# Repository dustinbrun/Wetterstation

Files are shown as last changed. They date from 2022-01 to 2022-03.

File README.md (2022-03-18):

# Wetterstation
MQTT-Wetterstation mit Datenauswertung und -Darstellung in Node-Red sowie Aufzeichung durch Influx-DB.

Dieses Projekt besteht aus mehreren Teilen:

## 1. [Grundlagen: VEML 6070 Sensor, UV-Index Berechnung](VEML_6070/README.md)
## 2. [Bresser Wetterstation MQTT-Anbindung mit RTL-433](rtl_433_Bresser/README.md)
## 3. [Erweiterung der Bresser Wetterstation: ESP8266-Wettersensoren](ESP8266/README.md)
## 4. [Zusatzinfos: verwendete Berechnungsformeln](Berechnungsfunktionen.md)

<br><br>
<p xmlns:dct="http://purl.org/dc/terms/" xmlns:cc="http://creativecommons.org/ns#" class="license-text">This work by <span property="cc:attributionName">Dustin Brunner</span> is licensed under <a rel="license" href="https://creativecommons.org/licenses/by/4.0">CC BY 4.0</a></p>

<br />Dieses Werk von <span xmlns:cc="http://creativecommons.org/ns#" property="cc:attributionName">Dustin Brunner</span> ist lizenziert unter einer <a rel="license" href="http://creativecommons.org/licenses/by/4.0/">Creative Commons Namensnennung 4.0 International Lizenz</a>.

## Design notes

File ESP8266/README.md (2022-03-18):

# ESP8266 MQTT Wetterstation

Wie man eine Wetterstation basierend auf einem ESP8266 baut...

Der ESP verbindet sich per WLAN mit einem MQTT-Server und sendet die Messwerte als JSON (alle 10 Minuten), welche dann in Node-Red empfangen und verarbeitet werden. Zusätzlich werden die Daten in eine Influx-DB Datenbank geschrieben und können in Grafana visualisiert werden.

Diese Wetterstation kann als Erweiterung der Bresser-Wetterstation gesehen werden. Es werden Funktionen hinzugefügt, welche über die Bresser-Wetterstation nicht gemessen und empfangen werden können.

# Die Sensoren
| Sensor	| Protocol	| Values |
| --- |--- | --- |
| BME 280 | I2C | Temperatur (nicht genutzt da nicht exakt), Luftfeuchtigkeit (nicht genutzt da von Bresser-Station gemesssen), Luftdruck |
| 2x DS18B20 | OneWire Bus | Temperatur (2m und 0m Höhe) |
| BH1750 | I2C | Helligkeit |
| Rain sensor | Analog in | Regen ja/nein |
| VEML6070 | I2C | UV-Intensität (daraus kann der UV-Index berechnet werden) |

<br>

# Hardware
Es wird ein WeMos D1 Mini Board verwendet. Das PCB-Layout passt (nur) für dieses Board.
## Schaltplan
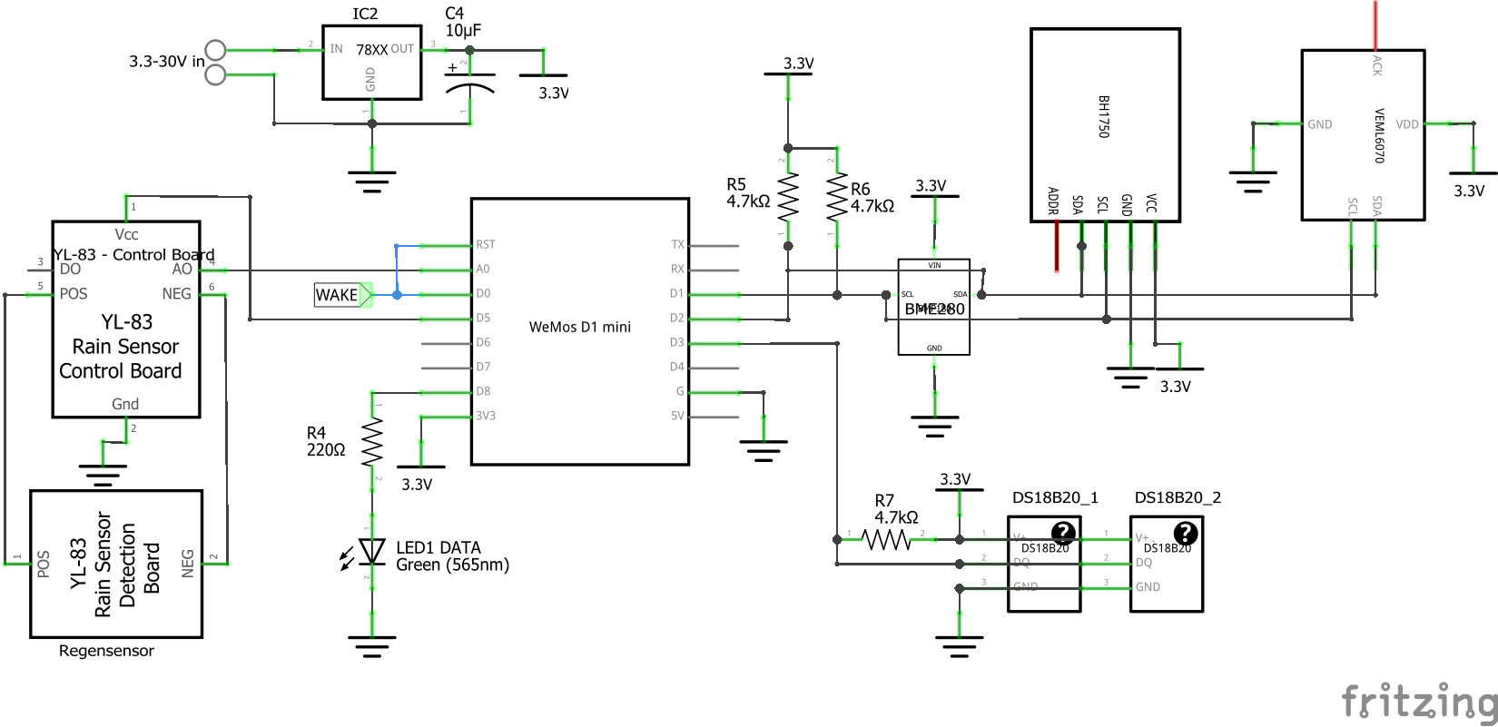
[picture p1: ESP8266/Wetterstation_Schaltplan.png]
[](Wetterstation_Schaltplan.png)

## Hauptplatine
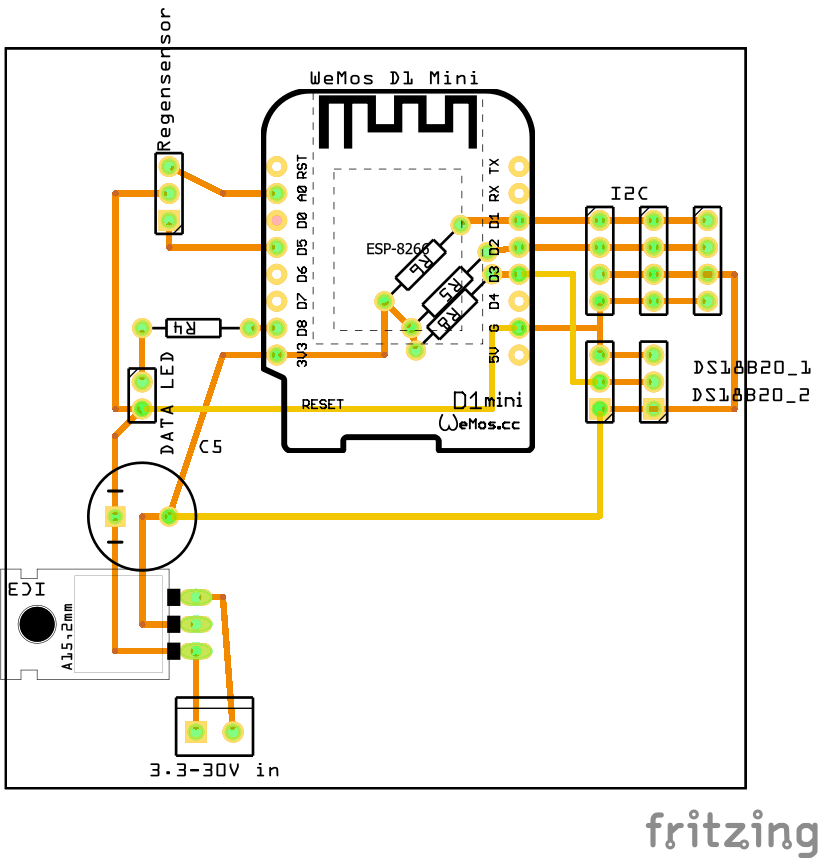
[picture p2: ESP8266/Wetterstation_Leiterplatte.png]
[](Wetterstation_Leiterplatte.png)

## 3D gedruckte Teile
Im Internet habe ich einen sog. Stevenson-Screen gefunden, welcher als Sonnenschutz-Gehäuse für den BME280 und die DS18B20 Sensoren dient.

Für die beiden Lichtsensoren habe ich jeweils ein Gehäuse erstellt, welche z.B. mit einem Stück Plexiglas geschlossen oder für noch besseren Feuchtigkeitsschutz mit transparenten Epoxidharz ausgegossen werden können. 
Die Modelle können aus der GitHub repository heruntergeladen werden. Das Lichtsensor Gehäuse ist auch auf Tinkercad verfügbar:  https://www.tinkercad.com/things/6c97AcGgvdE 

<br>

# Software
## ESP8266
-	Es wird bei jeder Messung ein Mittelwert aus 3 Messungen gebildet
-	Der Luftdruck auf NN-Niveau wird berechnet. (Im Programmcode muss die Aufstellhöhe der Station angepast werden, damit dieser Wert korrekt berechnet werden kann)
-	Es sind einige Debugging-Funktionen implementiert: ESP Reset, Ping/Pong, WIFI Signalstärke
-	Debug LED
bootup: ein
nach Initialisierung: blinkt 2x
error, MQTT nicht verbunden: dauer ein
-	Damit die DS18B20 Sensoren funktionieren müssen die Sensoradressen im Code angepasst werden. Diese Adressen können mit Beispielcode `oneWireSearch.ino` der DallasTemperature Bibiliothek in Erfahrung gebracht werden.
- Alle benötigten Bibiliotheken sind im Code verlinkt und können von dort heruntergeladen werden.

Achtung: Damit die Datenübertragung mit JSON funktioniert muss die zulässige Paketgröße `MQTT_MAX_PACKET_SIZE` in der `PubSubClient.h` Datei auf `1024` erhöht werden. Diese Datei ist unter Windows zu finden unter: `C:\Users\*YOUR_USERNAME*\Documents\Arduino\libraries\pubsubclient-master\src\PubSubClient.h`

## Datenverarbeitung: Node-Red
Die Auswertung der Messwerte erfolgt in Node-Red.
Ich habe einen Flow erstellt, welcher die Werte im Node-Red Dashboard grafisch darstellt sowie in eine Influx-DB Datenbank schreibt. Somit ist eine weitere Auswertung mit Grafana möglich. In Node-Red wird ebenfalls die Berechnung des UV-Risikofaktors (UV-Index) durchgeführt. Die Messwerte werden in globale Variablen geschieben, sodass sie innerhalb von Node-Red weiterverwendet werden können (z.B. für das [MQTT Weather Display](https://github.com/dustinbrun/MQTT-Weather-display))

[Screenshot des Node-Red Flows](Node-Red/node-red-flow.PNG)

Der Flow kann aus der Github Repository heruntergeladen werden.

# Quellen
-	https://github.com/jp112sdl/HB-UNI-Sen-WEA 
-	Rain sensor:	https://www.heise.de/developer/artikel/Darf-es-etwas-mehr-sein-Anschluss-von-Umweltsensoren-3339616.html 
-	MQTT: https://randomnerdtutorials.com/esp8266-and-node-red-with-mqtt/ 
-	BME280, debug functions: https://github.com/adlerweb/ESP8266-BME280-Multi/blob/master/src/main.cpp 
-	Stevenson Screen: https://www.thingiverse.com/thing:2755149 
-	Weitere Quellen (Bibiliotheken etc.) sind im Code verlinkt

<br><br>
<p xmlns:dct="http://purl.org/dc/terms/" xmlns:cc="http://creativecommons.org/ns#" class="license-text">This work by <span property="cc:attributionName">Dustin Brunner</span> is licensed under <a rel="license" href="https://creativecommons.org/licenses/by/4.0">CC BY 4.0</a></p>

<br />Dieses Werk von <span xmlns:cc="http://creativecommons.org/ns#" property="cc:attributionName">Dustin Brunner</span> ist lizenziert unter einer <a rel="license" href="http://creativecommons.org/licenses/by/4.0/">Creative Commons Namensnennung 4.0 International Lizenz</a>.

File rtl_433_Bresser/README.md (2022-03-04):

# Bresser Wetterstation MQTT
Viele Wetterstationen können mit Hilfe der Software rtl_433 emfangen werden.
rtl_433 wird hierbei als Brücke zwischen dem Signal der Wetterstation (868MHz) und dem MQTT-Server verwendet.
Ich verwende eine `Bresser 5-in-1 Wetter Center`-Station ([Link](https://www.bresser.de/Wetter-Zeit/BRESSER-5-in-1-Wetter-Center-schwarz.html)). rtl_433 ist aber ebenfalls mit vielen anderen Wettersationen kompatibel. Dazu einfach einen Blick in die Dokumentation werfen.

Der Empfang erfolgt mit Hilfe eines SDR-USB Sticks (auch ein DVBT-Stick mit RTL2832-Chipsatz ist möglich).

------------------

# Installation von rtl_433

Link zur Software: https://github.com/merbanan/rtl_433

Die Software kann z.B. auf einem Raspberry Pi oder innerhalb einer Virtuellen Maschine (VM, Ubuntu 20.04 server) erfolgen.

rtl_433 kann als Linux-Paket installiert werden (unter Debian mit `apt-get install rtl-433`). In meinem Fall konnte mit dieser Version jedoch keine erfolgreiche Decodierung erreicht werden. Deshalb der Weg über die manuelle Compillierung, welche bei mir die Wetterstation auf Anhieb erfolgreich empfangen konnte.

Zur Verwendung des SDR-Sticks zunächst folgende Vorkehrungen treffen:

In die Datei
```
sudo nano /etc/modprobe.d/blacklist.conf
```
folgende Einträge ergänzen:
```
# Blacklist DVBT-SDR Stick (disable the Stick for DVBT)
blacklist dvb_usb_rtl28xxu
blacklist rtl2832
blacklist rtl2830
```

Nun kann der SDR-Stick eingesteckt und mit der eigentlichen Installation begonnen werden. Die hier angegeben Paketversionen müssen nicht zwangsläufig verwendet werden funktionierten in meinem Fall jedoch auf Anhieb.
```
sudo apt-get install git libtool=2.4.6-14 libusb-1.0-0-dev=2:1.0.23-2build1 librtlsdr-dev=0.6.0-3 rtl-sdr=0.6.0-3 build-essential cmake pkg-config

git clone https://github.com/merbanan/rtl_433.git
cd rtl_433/
mkdir build
cd build
cmake ..
make
sudo make install
```

Die Funtkion des SDR-Sticks kann mit Hilfe des Befehls `rtl_test -t` geprüft werden.

# Testen des Empfangs
Als Antenne kann bei geringer Entfernung zur Wetterstation die dem DVBT-Stick mitgelieferte Antenne verwendet werden. 
Anderenfalls empfiehlt es sich eine `868MHz` Groundplane-Antenne zu bauen (Quelle: https://www.darc.de/fileadmin/filemounts/distrikte/o/ortsverbaende/38/Downloads/Bericht_868MHz_Antennen_V2.0.pdf):

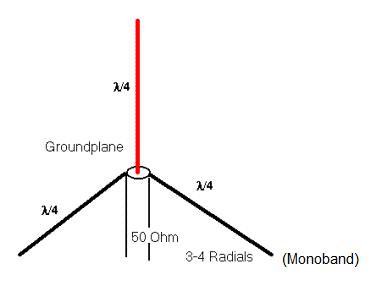
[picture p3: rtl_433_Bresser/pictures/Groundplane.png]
[](pictures/Groundplane.png)
([Bildquelle](http://sites.prenninger.com/elektronik/dvb-t-antennen/groundplane))

Für die Frequenz `868MHz` beträgt die Länge eines einzelnen Drahtes `lambda/4 = 1/4 * 300/868MHz * 0.96 = 8,29cm`.

Mit der passenden Antenne kann nun ein erster Empfangstest stattfinden:

```
rtl_433 -f 868M
```
Nach wenigen Sekunden/Minuten sollte ein erfolgreicher Empfang zustande gekommen sein. Die Ausgabe zeigt die Decodierten Messwerte:
```
time      : 2021-12-30 10:05:47
model     : Bresser-6in1  id        : 27384665
channel   : 0             Battery   : 1             Temperature: 19.8 C
Humidity  : 53            Sensor type: 1            Wind Gust : 0.8 m/s
Wind Speed: 0.8 m/s       Direction : 144           Integrity : CRC
```
Es kann teilweise vorkommen, dass in einer Nachricht nicht alle Messwerte gesendet werden.
Der Empfang kann mit `STRG-C` beendet werden.

# Produktivbetrieb mit MQTT
Die Einstellungen für den Betrieb werden in einer Konfigurationsdatei festgelegt. Dafür wird zunächst die Beispieldatei in das Programmverzeichnis kopiert und anschließend geöffnet.
```
sudo mkdir /etc/rtl_433
sudo cp conf/rtl_433.example.conf /etc/rtl_433/rtl_433.conf
sudo nano /etc/rtl_433/rtl_433.conf
```
In dieser Datei folgende Zeilen auskommentieren und anpassen:
```
frequency     868M          # Empfangsfrequenz der Wetterstation
sample_rate   1000000
report_meta   time:iso      # Fomat des Zeitstempels ISO
output        mqtt://---MQTT-SERVER-IP---:1883,user=USERNAME,pass=PASSWORD,retain=0,devices=rtl_433[/protocol]       # Ausgabe mit MQTT
```
Achtung: Bei dieser Art der Konfiguration kann es vorkommen, dass auch andere Wettersationen des gleichen Typs empfangen werden, sofern sie in Reichweite des Empfängers sind. Dies kann durch einen Abgleich der `id` der eigenen Station vermieden werden. Zu beachten ist dabei jedoch, dass sich die id nach jedem Reset bzw. Batteriewechsel ändert und damit jedes mal eine erneute Konfigurationsänderung nöitg ist.

Damit nur die Eigene Wetterstation (bzw. nur Sationen des gleichen Typs wie die eigene) empfangen wird, können in der Datei alle Protokolle außer das benötigte auskommentiert (`#` vor jede Zeile) oder gelöscht werden. Die einzige benötigte Zeile für diese Wetterstation muss erhalten bleiben:
```
protocol 172 # Bresser Weather Center 6-in-1, 7-in-1 indoor, new 5-in-1, 3-in-1 wind gauge, Froggit WH6000, Ventus C8488A
```

Nun kann diese Datei gespeichert und geschlossen werden. 

Es wird zuletzt noch der automatische Start beim Hochfahren konfiguriert:
```
sudo nano /etc/systemd/system/rtl_433-mqtt.service
```
In diese Datei wird der folgende Inhalt eingefügt und gespeichert:
```
[Unit]
Description=rtl_433 to MQTT publisher
After=network.target
[Service]
ExecStart=/usr/local/bin/rtl_433
Restart=always
RestartSec=5
[Install]
WantedBy=multi-user.target
```
Nun kann der Autostart aktiviert werden:
```
sudo systemctl enable rtl_433-mqtt.service
sudo systemctl start rtl_433-mqtt.service
sudo systemctl status rtl_433-mqtt.service
```
(Eine Deaktivierung kann mit `sudo systemctl disable rtl_433-mqtt.service` erfolgen.)

rtl_433 erzeugt nun für jeden Messwert eine MQTT-Nachricht. Der Name des MQTT-Topics entspricht dabei dem Messwertname, z.B. `rtl_433/172/wind_avg_m_s` oder `rtl_433/172/temperature_C`.

# Datenverarbeitung mit Node-Red
rtl_433 erzeugt bei jeder Nachricht für jeden Messwert eine MQTT-Nachricht, welche mit Node-Red weiterverarbeitet werden kann. Ich habe einen Node-Red-Flow erstellt, welcher die Messwerte im Node-Red-Dashboard darstellt sowie in eine Influx-DB Datenbank schreibt. Somit ist auch eine Visualisierung mit Grafana möglich. In Node-Red erfolgt ebenfalls die Berechnung von Taupunkt und Hitzeindex (gefühlte Temperatur) aus den Messwerten sowie eine Umrechung der Windgeschwindigkeit in km/h und eine entsprechende Windstärke (Beaufortskala). 

[Screenshot des Node-Red-Flows](pictures/node_red_flow.png)

Der Flow (`wetter_bresser_node_red_flow.json`) kann aus der Github-Repository heruntergeladen und importiert werden. Es werden folgende Erweiterungs-Nodes benötigt: node-red-dashboard, node-red-contrib-influxdb und node-red-contrib-calculate.

<br>
<br>
<p xmlns:dct="http://purl.org/dc/terms/" xmlns:cc="http://creativecommons.org/ns#" class="license-text">This work by <span property="cc:attributionName">Dustin Brunner</span> is licensed under <a rel="license" href="https://creativecommons.org/licenses/by/4.0">CC BY 4.0</a></p>

<br />Dieses Werk von <span xmlns:cc="http://creativecommons.org/ns#" property="cc:attributionName">Dustin Brunner</span> ist lizenziert unter einer <a rel="license" href="http://creativecommons.org/licenses/by/4.0/">Creative Commons Namensnennung 4.0 International Lizenz</a>.

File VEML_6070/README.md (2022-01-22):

# VEML6070 UV Sensor

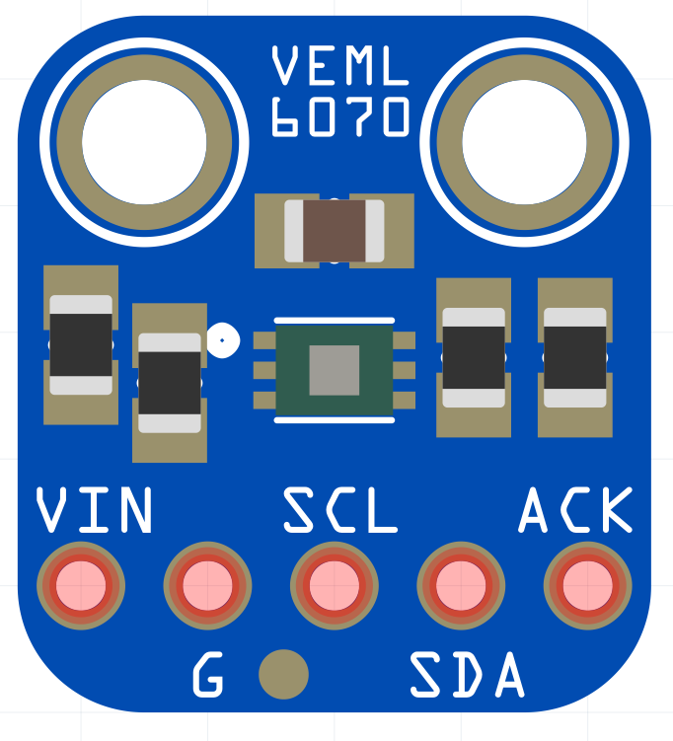
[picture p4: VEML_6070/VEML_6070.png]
[](VEML_6070.png)

The VEML6070 is a UV sensor with I2C-Interface.
It measures the UV light level but **NOT** the UV-Index. However, it is possible to convert the sensor readings to an equivalent UV-risk level/UV-Index.

> Unlike the Si1145 (http://adafru.it/1777), this sensor will not give you UV Index readings. However, the Si1145 does UV Index approximations based on light level not true UV sensing. The VEML6070 in contrast does have a real light sensor in the UV spectrum.

## Using the Sensor with Arduino
The sensor can be easily connected to the I2C pins of the Arduino (for Arduino UNO + Nano these are the pins A4 and A5).

To read the measurements the `Adafruit_VEML6070`-Library can be used. 
It can be installed directly via the Arduino Library Manager. Alternatively, it can be downloaded from GitHub: https://github.com/adafruit/Adafruit_VEML6070

## Convert measurements to UV-Risk level
The conversion is implemented in the equivalent Adafruit library for Circuit Python  (https://github.com/adafruit/Adafruit_CircuitPython_VEML6070). However it is not implemented in the Arduino version.

I adapted the Circuit Python code and created an extended example sketch with risk-level-conversion.

```
String convert_to_risk_level(int reading) 
{
  int integration_time = 4;   //available for Integration-Time 1, 2, 4
                              // MUST be adjusted according to the set integration time
  reading = reading / integration_time;

  String risk_level;

  if(reading <= 560)
      risk_level = "LOW (UV 0-2)";
  else if(reading > 560 && reading <= 1120)
      risk_level = "Moderate (UV 3-5)";
  else if(reading > 1120 && reading <= 1494)
      risk_level = "High (UV 6-7)";
  else if(reading > 1494 && reading <= 2054)
      risk_level = "Very High (UV 8-10)";
  else if(reading > 2054 && reading <= 9999)
      risk_level = "Extreme (UV >10)";
  else
      risk_level = "ERROR";

  return risk_level;
}

```

## You can the full example sketch [here](./vemltest_extended/vemltest_extended.ino).

<br>
References/Sources: https://cdn-learn.adafruit.com/downloads/pdf/adafruit-veml6070-uv-light-sensor-breakout.pdf

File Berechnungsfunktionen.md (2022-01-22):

# Wetterstation Berechnungen
Hier sind einige nützliche Berechnungsfunktionen und Formeln zu finden, welch ich in meiner Wetterstation verwende. Die Berechnungsfunktionen sind in Javascript zur Verwendung in Node-Red geschieben, können jedoch einfach auch für andere Plattformen angepasst werden (z.B. Arduino).

Die Quellen sind jeweils verlinkt.

# Taupunkt berechnen
Quelle: https://myscope.net/taupunkttemperatur/

Die Berechnung des Taupunktes erfolgt aus den Messwerten Temperatur (°C) und Luftfeuchtigkeit (%).

```
var calcdewpoint = function(celsius, humidity) {

  var a, b;
  if (celsius >= 0) {
    a = 7.5;
    b = 237.3;
  } else if (celsius < 0) {
    a = 7.6;
    b = 240.7;
  }

  // Sättigungsdampfdruck (hPa)
  var sdd = 6.1078 * Math.pow(10, (a * celsius) / (b + celsius));

  // Dampfdruck (hPa)
  var dd = sdd * (humidity / 100);

  // v-Parameter
  var v = Math.log10(dd / 6.1078);

  // Taupunkttemperatur (°C)
  var td = (b * v) / (a - v);
  
  //Runden 1 Nachkommastelle
  td =  Math.round(td * 10) / 10;
  
  return td;
}

msg.payload = calcdewpoint(12.45, 80);

return msg;
```
# Gefühlte Temperatur berechnen
Die Gefühlte Temperatur setzt sich aus zwei Berechnungsarten zusammen. Windchill (Temperatur kleiner als 10°C und Windgeschwindigkeit größer als 4.8km/h) und Hitzeindex (Temperatur größer als 26.7°C und Relative Luftfeuchte größer als 40%).

```

//Quelle:   https://myscope.net/windchill-gefuehlte-temperatur-berechnen/
//          https://de.wikipedia.org/wiki/Windchill
var calcwindchill = function(celsius, windspeed) {
  var windchill = 13.12 + 0.6215 * celsius - 11.37 * Math.pow(windspeed, 0.16) + 0.3965 * celsius * Math.pow(windspeed, 0.16);
  return windchill;
}

//Quelle:   https://myscope.net/hitzeindex-gefuehle-temperatur/
//          https://de.wikipedia.org/wiki/Hitzeindex
var calcheatindex = function(celsius, humidity) {
  return (-8.784695 + 1.61139411 * celsius + 2.338549 * humidity - 0.14611605 * celsius * humidity - 0.012308094 * celsius * celsius - 0.016424828 * humidity * humidity + 0.002211732 * celsius * celsius * humidity + 0.00072546 * celsius * humidity * humidity - 0.000003582 * celsius * celsius * humidity * humidity);
}

var Temperatur_2m = parseFloat(12.34);
var Luftfeuchte_rel = parseFloat(80);
var windkmh = parseFloat(2.45);

if (Temperatur_2m <= 10 && windkmh >= 4.8) 
{
   msg.payload = calcwindchill(Temperatur_2m, windkmh);
   msg.topic = "123";
}
else if (Temperatur_2m >= 26.7 && Luftfeuchte_rel >= 40) 
{
   msg.payload = calcheatindex(Temperatur_2m, Luftfeuchte_rel);
   msg.topic = "246";
}
else //Keine der beiden Formeln ist definiert
{
   //msg.payload = -1;
   msg.payload = Temperatur_2m;
}
 
//Runden 1 Nachkommastelle
msg.payload =  Math.round(msg.payload * 10) / 10;

return msg;
```

# Absolute Luftfeuchtigkeit
Eine Umrechnung von Relativer (in %) in Absolute Luftfeuchtigkeit (in g/m^3).

```
// Relative to absolute humidity
// Based on https://carnotcycle.wordpress.com/2012/08/04/how-to-convert-relative-humidity-to-absolute-humidity/
var absoluteHumidity = function(temperature, humidity) {
  return (13.2471*Math.pow(2.7182818,17.67*temperature/(temperature+243.5))*humidity/(273.15+temperature));
}

var Temperatur_2m = parseFloat(12.34);
var Luftfeuchte_rel = parseFloat(45);

msg.payload = absoluteHumidity(Temperatur_2m, Luftfeuchte_rel);

//Runden 1 Nachkommastelle
msg.payload =  Math.round(msg.payload * 10) / 10;

return msg;
```

# Windgeschwindigkeit Meter pro Sekunde in Kilometer pro Stunde
Eine Umrechnung der Windgeschwindigkeit vom m/s in km/h sowie runden des Ergebnisses auf eine Nachkommastellen.
```
msg.payload =  Math.round(msg.payload * 3.6 * 10) / 10;

return msg;
``` 

# Windgeschwindigkeit von Kilometer pro Stunde in Windstärke/Beaufortskala umrechnen
Referenz: https://wetterkanal.kachelmannwetter.com/woher-kommt-die-beaufortskala/
Die Berechnungen beziehen sich auf die Einheit m/s. 

```
var windmax = parseFloat(msg.payload) / 3.6;

var windstarkewort = {};
windstarkewort.topic = "Windstärke_Wort";

var windstarkebft = {};
windstarkebft.topic = "Windstärke_bft";

if (windmax < 0.3) {
    windstarkebft.payload = 0;
    windstarkewort.payload = "Windstille";
  }
  else if (windmax >= 0.3 && windmax < 1.6) {
    windstarkebft.payload = 1;
    windstarkewort.payload = "leiser Zug";
  }
  else if (windmax >= 1.6 && windmax < 3.4 ) {
    windstarkebft.payload = 2;
    windstarkewort.payload = "leichte Brise";
  }
  else if (windmax >= 3.4 && windmax < 5.5) {
    windstarkebft.payload = 3;
    windstarkewort.payload = "schwache Brise";
  }
  else if (windmax >= 5.5 && windmax < 8.0 ) {
    windstarkebft.payload = 4;
    windstarkewort.payload = "mäßige Brise";
  }
  else if (windmax >= 8.0 && windmax < 10.8 ) {
    windstarkebft.payload = 5;
    windstarkewort.payload = "frische Brise";
  }
  else if (windmax >= 10.8 && windmax < 13.9 ) {
    windstarkebft.payload = 6;
    windstarkewort.payload = "starker Wind";
  }
  else if (windmax >= 13.9 && windmax < 17.2 ) {
    windstarkebft.payload = 7;
    windstarkewort.payload = "steifer Wind";
  }
  else if (windmax >= 17.2 && windmax < 20.8 ) {
    windstarkebft.payload = 8;
    windstarkewort.payload = "stürmischer Wind";
  }
  else if (windmax >= 20.8 && windmax < 24.5 ) {
    windstarkebft.payload = 9;
    windstarkewort.payload = "Sturm";
  }
  else if (windmax >= 24.5 && windmax < 28.5 ) {
    windstarkebft.payload = 10;
    windstarkewort.payload = "schwerer Sturm";
  }
  else if (windmax >= 28.5 && windmax < 32.7 ) {
    windstarkebft.payload = 11;
    windstarkewort.payload = "orkanartiger Sturm";
  }
  else if (windmax >= 32.7) {
    windstarkebft.payload = 12;
    windstarkewort.payload = "Sturm";
  }

return [windstarkewort, windstarkebft];

```

# Windrichtung "Grad in Wort"
Eine Umrechnung einer Windrichtung in Grad (0° entpsricht Nord) in Himmelsrichtungen (z.B. NO, S usw.).

```
var windrichtung = parseInt(msg.payload);

var windrichtungwort = {};
windrichtungwort.topic = "Windrichtung_Wort";

if (windrichtung >= 348 &&  windrichtung < 12) {
    windrichtungwort.payload = "N";
  }
  else if (windrichtung >= 12 && windrichtung < 35) {
    windrichtungwort.payload = "NNO";
  }
  else if (windrichtung >= 35 && windrichtung < 57) {
    windrichtungwort.payload = "NO";
  }
  else if (windrichtung >= 57 && windrichtung < 80) {
    windrichtungwort.payload = "NOO";
  }
  else if (windrichtung >= 80 && windrichtung < 102) {
    windrichtungwort.payload = "O";
  }
  else if (windrichtung >= 102 && windrichtung < 125) {
    windrichtungwort.payload = "SOO";
  }
  else if (windrichtung >= 125 && windrichtung < 147) {
    windrichtungwort.payload = "SO";
  }
  else if (windrichtung >= 147 && windrichtung < 170) {
    windrichtungwort.payload = "SSO";
  }
  else if (windrichtung >= 170 && windrichtung < 192) {
    windrichtungwort.payload = "S";
  }
  else if (windrichtung >= 192 && windrichtung < 215) {
    windrichtungwort.payload = "SSW";
  }
  else if (windrichtung >= 215 && windrichtung < 237) {
    windrichtungwort.payload = "SW";
  }
  else if (windrichtung >= 237 && windrichtung < 260) {
    windrichtungwort.payload = "SWW";
  }
  else if (windrichtung >= 260 && windrichtung < 282) {
    windrichtungwort.payload = "W";
  }
  else if (windrichtung >= 282 && windrichtung < 305) {
    windrichtungwort.payload = "NWW";
  }
  else if (windrichtung >= 305 && windrichtung < 327) {
    windrichtungwort.payload = "NW";
  }
  else if (windrichtung >= 327 && windrichtung < 348) {
    windrichtungwort.payload = "NNW";
  }
  else {
    windrichtungwort.payload = "???";
  }

return windrichtungwort;
```

<br><br>
<p xmlns:dct="http://purl.org/dc/terms/" xmlns:cc="http://creativecommons.org/ns#" class="license-text">This work by <span property="cc:attributionName">Dustin Brunner</span> is licensed under <a rel="license" href="https://creativecommons.org/licenses/by/4.0">CC BY 4.0</a></p>

<br />Dieses Werk von <span xmlns:cc="http://creativecommons.org/ns#" property="cc:attributionName">Dustin Brunner</span> ist lizenziert unter einer <a rel="license" href="http://creativecommons.org/licenses/by/4.0/">Creative Commons Namensnennung 4.0 International Lizenz</a>.

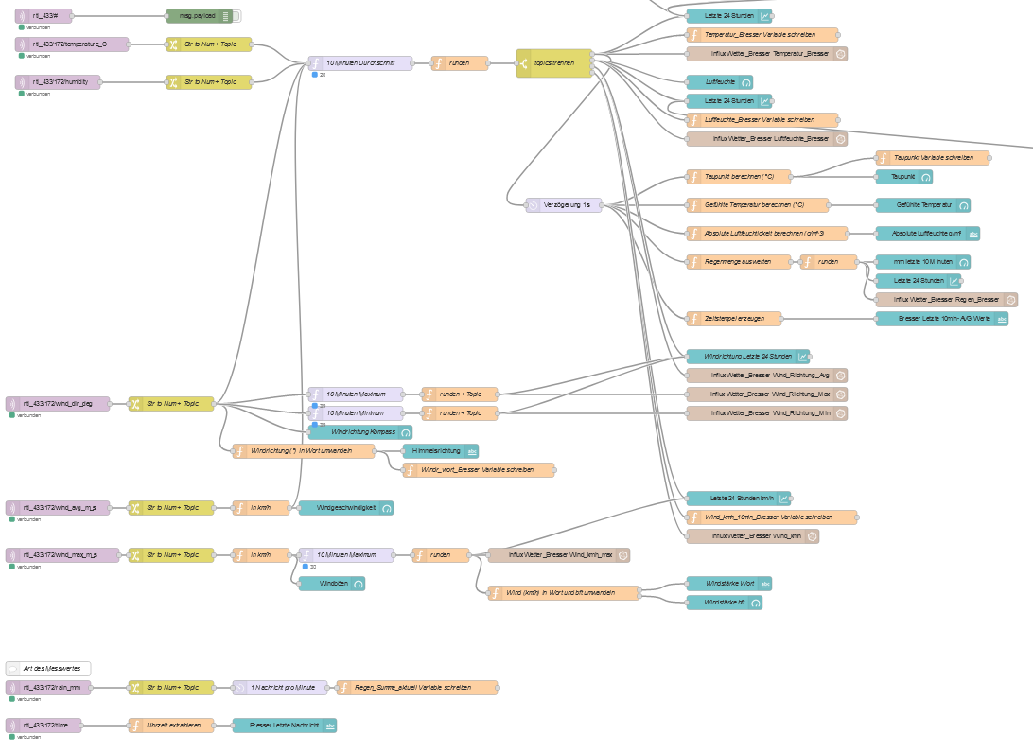
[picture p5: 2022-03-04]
rtl_433_Bresser/pictures/node_red_flow.png

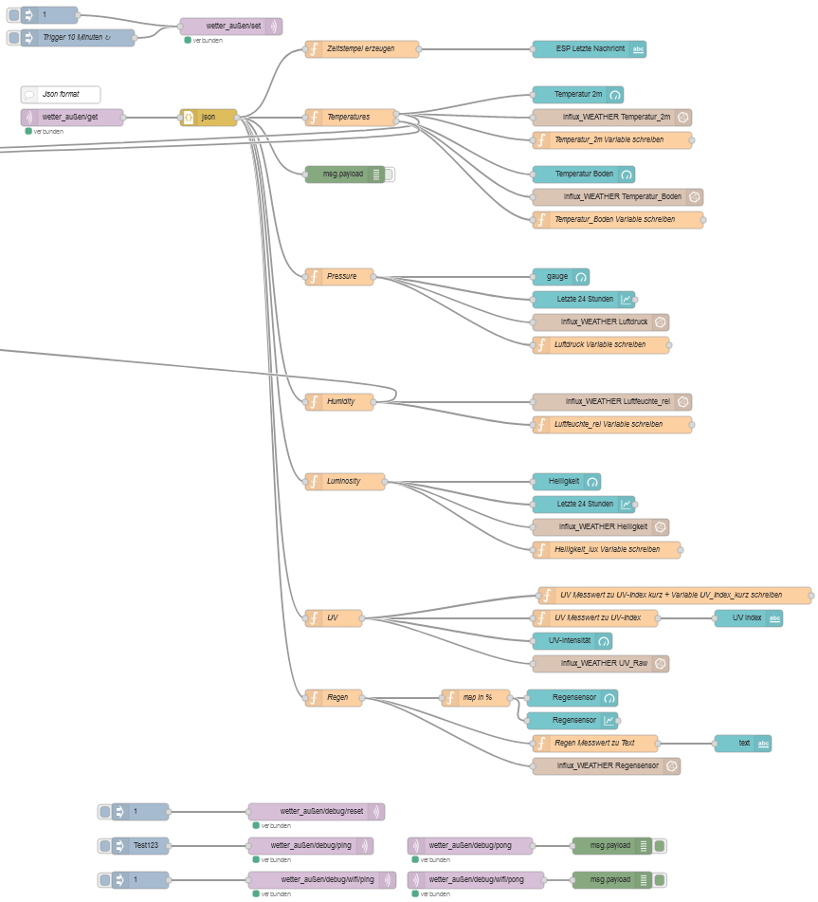
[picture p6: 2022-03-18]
ESP8266/Node-Red/node-red-flow.PNG

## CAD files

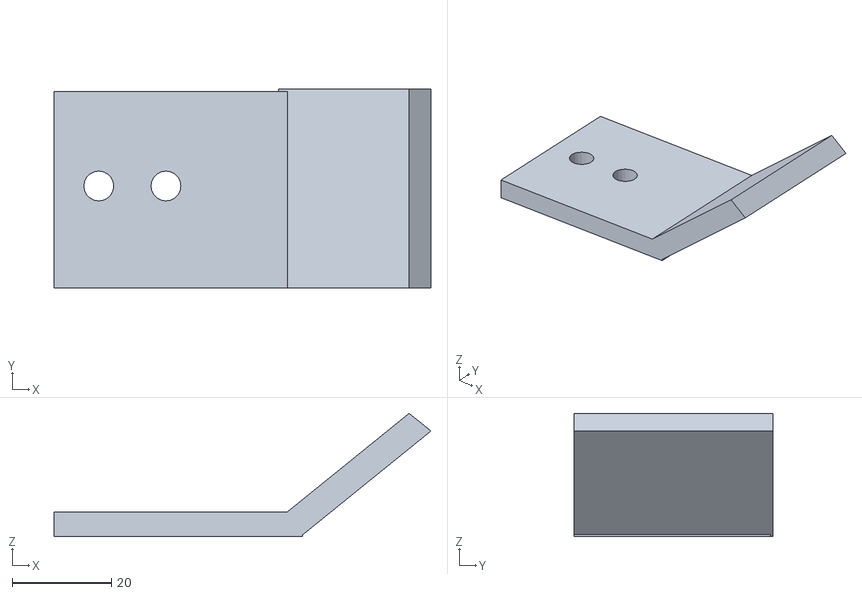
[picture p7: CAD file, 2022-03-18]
ESP8266/3D_models/Rain_sensor.stl
75.8 x 40.0 x 24.8

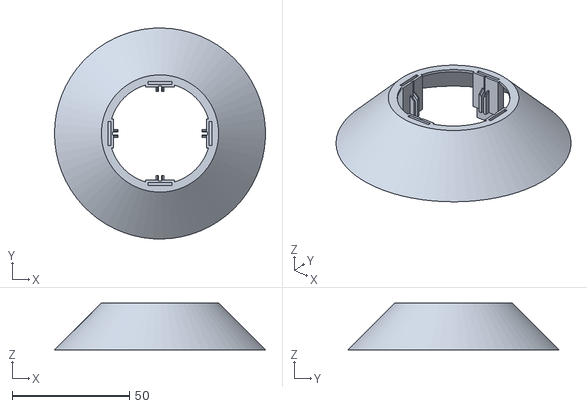
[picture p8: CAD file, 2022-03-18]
ESP8266/3D_models/Stevenson_screen/rodek_4szt.stl
90.0 x 90.0 x 20.0

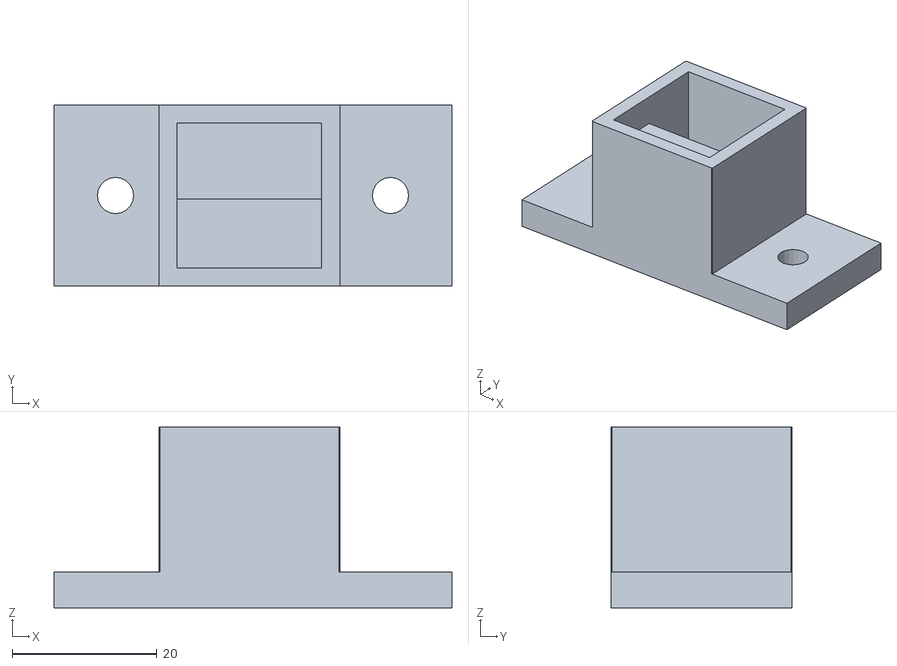
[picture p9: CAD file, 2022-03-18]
ESP8266/3D_models/Lightsensor_Case.stl
55.0 x 25.0 x 25.0

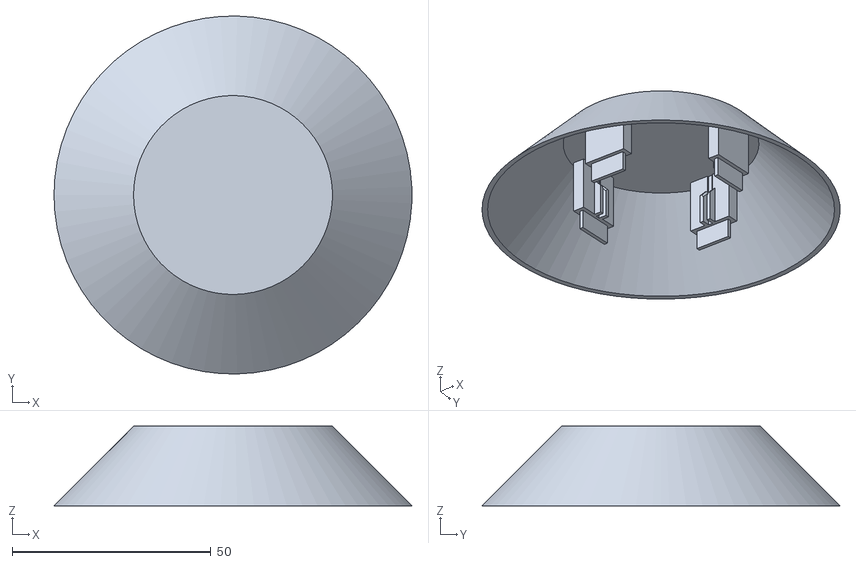
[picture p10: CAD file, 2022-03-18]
ESP8266/3D_models/Stevenson_screen/Góra_1szt.stl
90.0 x 90.0 x 20.0

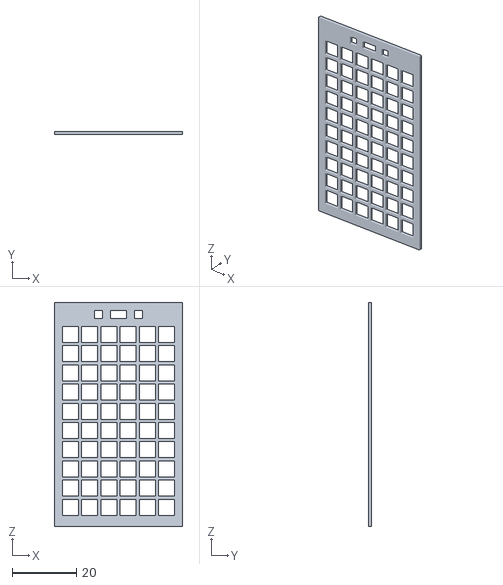
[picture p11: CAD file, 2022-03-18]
ESP8266/3D_models/Stevenson_screen/Siatka_1szt.stl
40.0 x 1.00 x 70.0

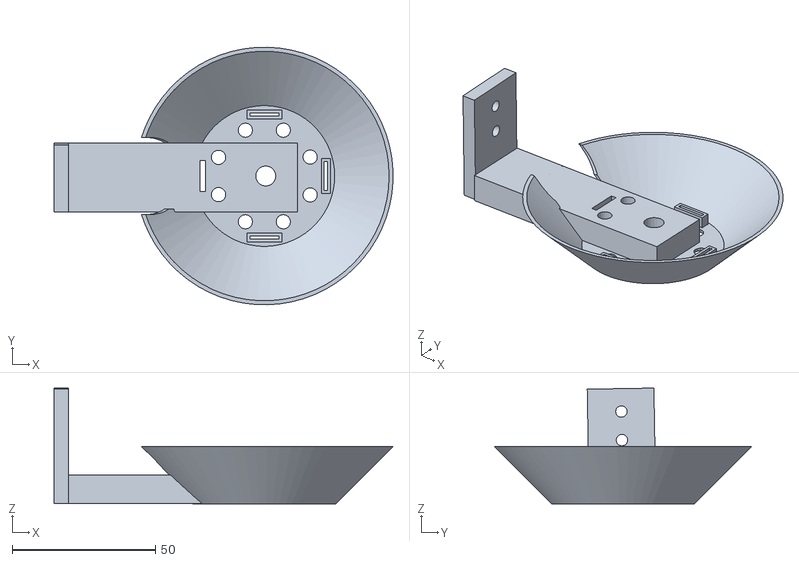
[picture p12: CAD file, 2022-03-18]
ESP8266/3D_models/Stevenson_screen/Stevenson_screen_base.stl
118.5 x 90.0 x 40.5

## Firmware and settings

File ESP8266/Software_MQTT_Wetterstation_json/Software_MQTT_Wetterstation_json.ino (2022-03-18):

/*
   WARNING:
   If you are not receiving the Json Messages you probably have to increase the
   MQTT_MAX_PACKET_SIZE in the PubSubClient.h file to at least 1024
   (Located on Windows at C:\Users\*YOUR_USERNAME*\Documents\Arduino\libraries\pubsubclient-master\src\PubSubClient.h)
*/


#include <Wire.h>
#include <Adafruit_Sensor.h>
#include <Adafruit_BME280.h> //https://github.com/adafruit/Adafruit_BME280_Library
#include <BH1750.h> //https://github.com/claws/BH1750
#include <ESP8266WiFi.h>
#include <PubSubClient.h> //https://github.com/knolleary/pubsubclient
#include <OneWire.h>
#include <DallasTemperature.h> //https://github.com/milesburton/Arduino-Temperature-Control-Library
#include <ArduinoJson.h> // https://github.com/bblanchon/ArduinoJson
#include "Adafruit_VEML6070.h"  // https://github.com/adafruit/Adafruit_VEML6070



  const char *ssid = "----WIFI_SSID_HERE----";
  const char *password = "----WIFI_PASSWORD_HERE----";

  //MQTT Server
  const char *mqtt_server = "----MQTT_SERVER_IP_HERE----";
  const char *mqtt_user = "----MQTT_USERNAME_HERE----";
  const char *mqtt_pass = "----MQTT_PASSWORD_HERE----";



uint8_t ds18b20_2m[8] = {0x28, 0xB4, 0x2A, 0xA7, 0x4D, 0x20, 0x01, 0x11}; //You need to adapt these addresses
uint8_t ds18b20_0m[8] = {0x28, 0xA9, 0x2F, 0x1C, 0x0B, 0x00, 0x00, 0xA8};

const int hoehe = 437; //Aufstellhoehe in m

//Pins
const int dataled = D8;
const int onewire = D3; //DS18B20
const int regensensorpin = A0;
const int regensensorpower = D5;

#define TEMPERATURE_PRECISION 11 //9-12 Bit for DS18B20 
/* 9-12 Bit
   9 - 0.5 Steps
   10 - 0.25 Steps
   11 - 0.125 Steps <- Best for this Case
   12 - 0.0625 Steps
*/

Adafruit_BME280 bme;
Adafruit_VEML6070 uvMeter = Adafruit_VEML6070();
BH1750 lightMeter;
WiFiClient espClient;
PubSubClient client(espClient);
OneWire oneWire(onewire);
DallasTemperature ds18b20(&oneWire);
StaticJsonBuffer<1024> jsonBuffer;


//Variablen
float temp = 0;
float bodentemp = 0;
float druck_sensorwert = 0;
float druck = 0;
float feuchte = 0;
float lux = 0;
int uv = 0;
float regensensorwert = 0;

void setup() {
  Serial.begin(115200);
  Serial.println("MQTT Wetterstation");

  pinMode(dataled, OUTPUT);
  pinMode(regensensorpin, INPUT_PULLUP);
  pinMode(regensensorpower, OUTPUT);
  digitalWrite(regensensorpower, LOW);

  ledon();
  delay(500);

  ds18b20.begin();
  ds18b20.setResolution(ds18b20_2m, TEMPERATURE_PRECISION);
  ds18b20.setResolution(ds18b20_0m, TEMPERATURE_PRECISION);

  //        SDA, SCL
  Wire.begin(D2, D1);

  if (! bme.begin(0x76))
  {
    Serial.println("Could not find BME280 sensor");
    //while (1) {}
  }
  else
  {
    Serial.println("BME280 initialized.");
  }


  if (! lightMeter.begin())
  {
    Serial.println("Could not find BH1750 sensor");
    //while (1) {}
  }
  else
  {
    Serial.println("BH1750 initialized.");
  }


  uvMeter.begin(VEML6070_4_T);
  /*
      possible integration times: -> adapt the convert_to_risk_level-function accordingly!
      VEML6070_HALF_T ~62.5ms
      VEML6070_1_T ~125ms
      VEML6070_2_T ~250ms
      VEML6070_4_T ~500ms

  */
  uv = uvMeter.readUV();
  if (uv == -1 || uv == 65535)
  {
    Serial.println("Could not find VEML6070 sensor");
    //while (1) {}
  }
  else
  {
    Serial.println("VEML6070 initialized.");
  }



  Serial.print("Connecting to ");
  Serial.println(ssid);
  WiFi.mode(WIFI_STA);
  WiFi.begin(ssid, password);
  while (WiFi.status() != WL_CONNECTED) {
    delay(500);
    Serial.print(".");
  }
  Serial.println("WiFi connected.");
  Serial.println("IP address: ");
  Serial.println(WiFi.localIP());

  client.setServer(mqtt_server, 1883);
  client.setCallback(callback);

  ledblink();
  Serial.println("-----Initialisierung beendet-----");
}

void loop() {
  if (!client.connected())
    reconnect();
  client.loop();

  delay(100);
}

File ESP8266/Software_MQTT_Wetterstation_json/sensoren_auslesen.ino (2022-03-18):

void readsensors() {
  ledon();
  digitalWrite(regensensorpower, HIGH);
  delay(50);

  temp = 0;
  bodentemp = 0;
  druck_sensorwert = 0;
  feuchte = 0;
  lux = 0;
  regensensorwert = 0;
  uv = 0;

  for (int i = 0; i < 3; ++i) {
    //BME280
    //temp += bme.readTemperature();
    druck_sensorwert += bme.readPressure();
    feuchte += bme.readHumidity();

    //BH1750
    lux += lightMeter.readLightLevel();

    //DS18B20
    ds18b20.requestTemperatures();
    bodentemp += ds18b20.getTempC(ds18b20_0m);
    temp += ds18b20.getTempC(ds18b20_2m);

    //VEML6070
    uv += uvMeter.readUV(); //measurement takes as long as the integration time is set

    //Regensensor
    regensensorwert += analogRead(regensensorpin);

    delay(100);
  }
  temp = temp /  3;
  druck_sensorwert = druck_sensorwert / 3;
  feuchte = feuchte / 3;
  lux = lux / 3;
  bodentemp = bodentemp / 3;
  uv = uv / 3;
  regensensorwert = regensensorwert / 3;
  digitalWrite(regensensorpower, LOW);

  //Rechnen
  //druck = (druck_sensorwert / 100) + (hoehe / 8.5);
  druck = druck_sensorwert / 100;
  druck = bme.seaLevelForAltitude(hoehe, druck);

  ledoff();
}
